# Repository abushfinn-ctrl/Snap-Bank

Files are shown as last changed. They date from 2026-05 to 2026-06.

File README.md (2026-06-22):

# Snap-Bank
A powerbank with a removable 18650 battery for quick "charges" on the go. I love the idea of this project because it allows you to only carry an extra or two 18650 batteries instead of having to carry a massive powerbank. This means that at school or scout camps I can keep a small powerbank in my pocket because I have really bad battery life on my phone, and I can still have the capacity of a 4 cell powerbank when I need via switching the batteries out. I also designed it that the battery holding can come fully out so you could carry an extra 18650 in the battery holder to keep it a little more protected, although I will probably end up printing a screw on case for the batteries. I also made it with a clear acrylic panel so I can see the cool internals that I spent time on.
# Final Product


# Pictures and Renders
Screenshot 2026-05-16 at 2 48 41 PM
Screenshot 2026-05-16 at 2 49 00 PM

# PCB
Screenshot 2026-05-16 at 2 46 15 PM
Screenshot 2026-05-16 at 2 47 12 PM
Screenshot 2026-05-16 at 2 46 44 PM

# BOM
|Part Number |Manufacturer Part Number|Description |Quantity|Unit Price CAD|Total Price CAD|Running total CAD|Unit Price USD|Total Price USD|Running total USD|Links |
|---|---|---|---|---|---|---|---|---|---|---|
|1276-1096-1-ND |CL21A106KOQNNNE |CAP CER 10UF 16V X5R 0805 |10 |$0.08 |$0.78 |$0.78 |$0.06 |$0.57 |$0.57 |https://www.digikey.ca/en/products/detail/samsung-electro-mechanics/CL21A106KOQNNNE/3886754 |
|1276-2909-1-ND |CL21A226MOQNNNE |CAP CER 22UF 16V X5R 0805 |5 |$0.39 |$1.95 |$2.73 |$0.28 |$1.42 |$1.98 |https://www.digikey.ca/en/products/detail/samsung-electro-mechanics/CL21A226MOQNNNE/3888567 |
|311-2.0ARCT-ND |RC0805JR-072RL |RES 2 OHM 5% 1/8W 0805 |4 |$0.15 |$0.60 |$3.33 |$0.11 |$0.44 |$2.42 |https://www.digikey.ca/en/products/detail/yageo/RC0805JR-072RL/728267 |
|311-20ARCT-ND |RC0805JR-0720RL |RES 20 OHM 5% 1/8W 0805 |2 |$0.15 |$0.30 |$3.63 |$0.11 |$0.22 |$2.64 |https://www.digikey.ca/en/products/detail/yageo/RC0805JR-0720RL/728281 |
|311-10KARCT-ND |RC0805JR-0710KL |RES 10K OHM 5% 1/8W 0805 |2 |$0.15 |$0.30 |$3.93 |$0.11 |$0.22 |$2.86 |https://www.digikey.ca/en/products/detail/yageo/RC0805JR-0710KL/728241 |
|311-5.1KARCT-ND |RC0805JR-075K1L |RES 5.1K OHM 5% 1/8W 0805 |10 |$0.05 |$0.45 |$4.38 |$0.03 |$0.33 |$3.18 |https://www.digikey.ca/en/products/detail/yageo/RC0805JR-075K1L/728338 |
|2073-USB4085-GF-ACT-ND |USB4085-GF-A |CONN RCPT USB2.0 TYPE C 16+8POS |2 |$1.31 |$2.62 |$7.00 |$0.95 |$1.90 |$5.09 |https://www.digikey.ca/en/products/detail/gct/USB4085-GF-A/9859662 |
|587-LAXHG6060YEL1R0NMRCT-ND|LAXHG6060YEL1R0NMR |FIXED IND 1UH 6.2A 13 MOHM SMD  |2 |$0.95 |$1.90 |$8.90 |$0.69 |$1.38 |$6.47 |https://www.digikey.ca/en/products/detail/taiyo-yuden/LAXHG6060YEL1R0NMR/17831610 |
|EG5350CT-ND |TL3305AF160QG |SWITCH TACTILE SPST-NO 0.05A 12V|2 |$0.31 |$0.62 |$9.52 |$0.23 |$0.45 |$6.92 |https://www.digikey.ca/en/products/detail/e-switch/TL3305AF160QG/5816181 |
|N/A |Digikey Shipping |Shipping for digikey |1 |$8.00 |$8.00 |$17.52 |$5.82 |$5.82 |$12.74 | |
|N/A |HST |Taxes for Digikey |1 |$2.28 |$2.28 |$19.80 |$1.66 |$1.66 |$14.40 | |
|IP5306 |Aliexpress |IP5306 from aliexpress (10 Pack)|1 |3.47 |3.47 |$23.27 |$2.52 |$2.52 |$16.92 |https://www.aliexpress.com/item/1005006842113401.html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 |
|18650 |Aliexpress |INR18650 25R 1865 2500Mah (4 Pack)|1 |19.66 |19.66 |$42.93 |$14.29 |$14.29 |$31.21 |https://www.aliexpress.com/item/1005009553868764.html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|

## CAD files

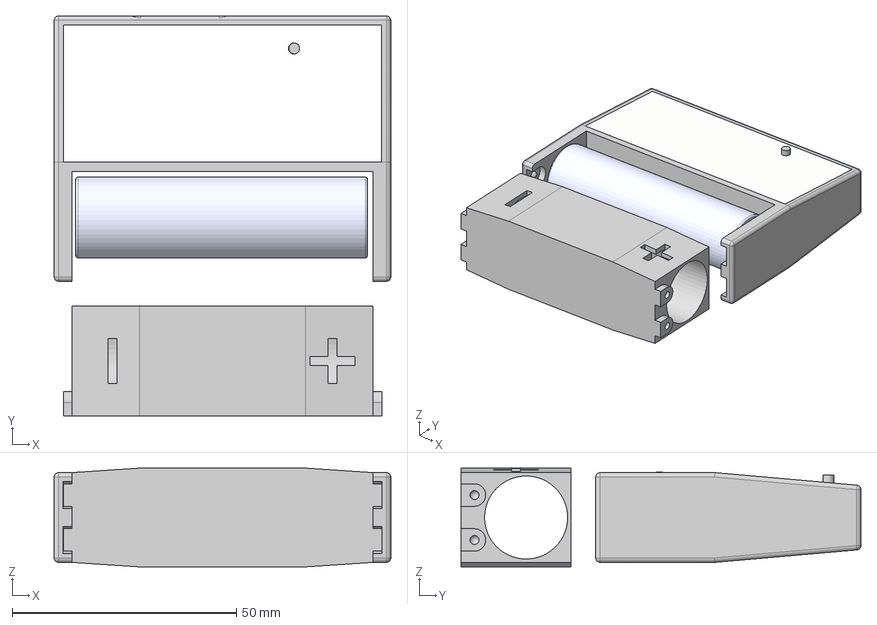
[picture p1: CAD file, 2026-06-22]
CAD/Powerbank.step
75.0 x 89.1 x 22.0 mm
LED_0805_2012Metric x 5
R_0805_2012Metric x 15
USB_C_Receptacle_GCT_USB4085 x 2
L_Chilisin_BWVS00606020
SW_SPST_TL3305A
Powerbank_PCB
battery 186501^battery 18650(2)_battery 18650
battery 186502^battery 18650(2)_battery 18650
battery 186503^battery 18650(2)_battery 18650
battery 186504^battery 18650(2)_battery 18650

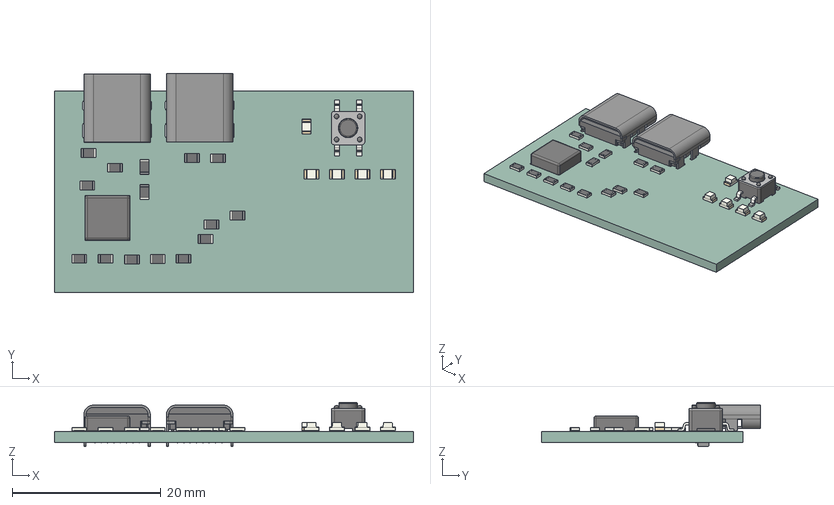
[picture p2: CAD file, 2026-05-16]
PCB/Snap-Bank/Powerbank.step
48.2 x 29.3 x 5.91 mm
LED_0805_2012Metric x 5
R_0805_2012Metric x 15
USB_C_Receptacle_GCT_USB4085 x 2
L_Chilisin_BWVS00606020
SW_SPST_TL3305A
Powerbank_PCB

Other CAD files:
CAD/SnapBank.f3z

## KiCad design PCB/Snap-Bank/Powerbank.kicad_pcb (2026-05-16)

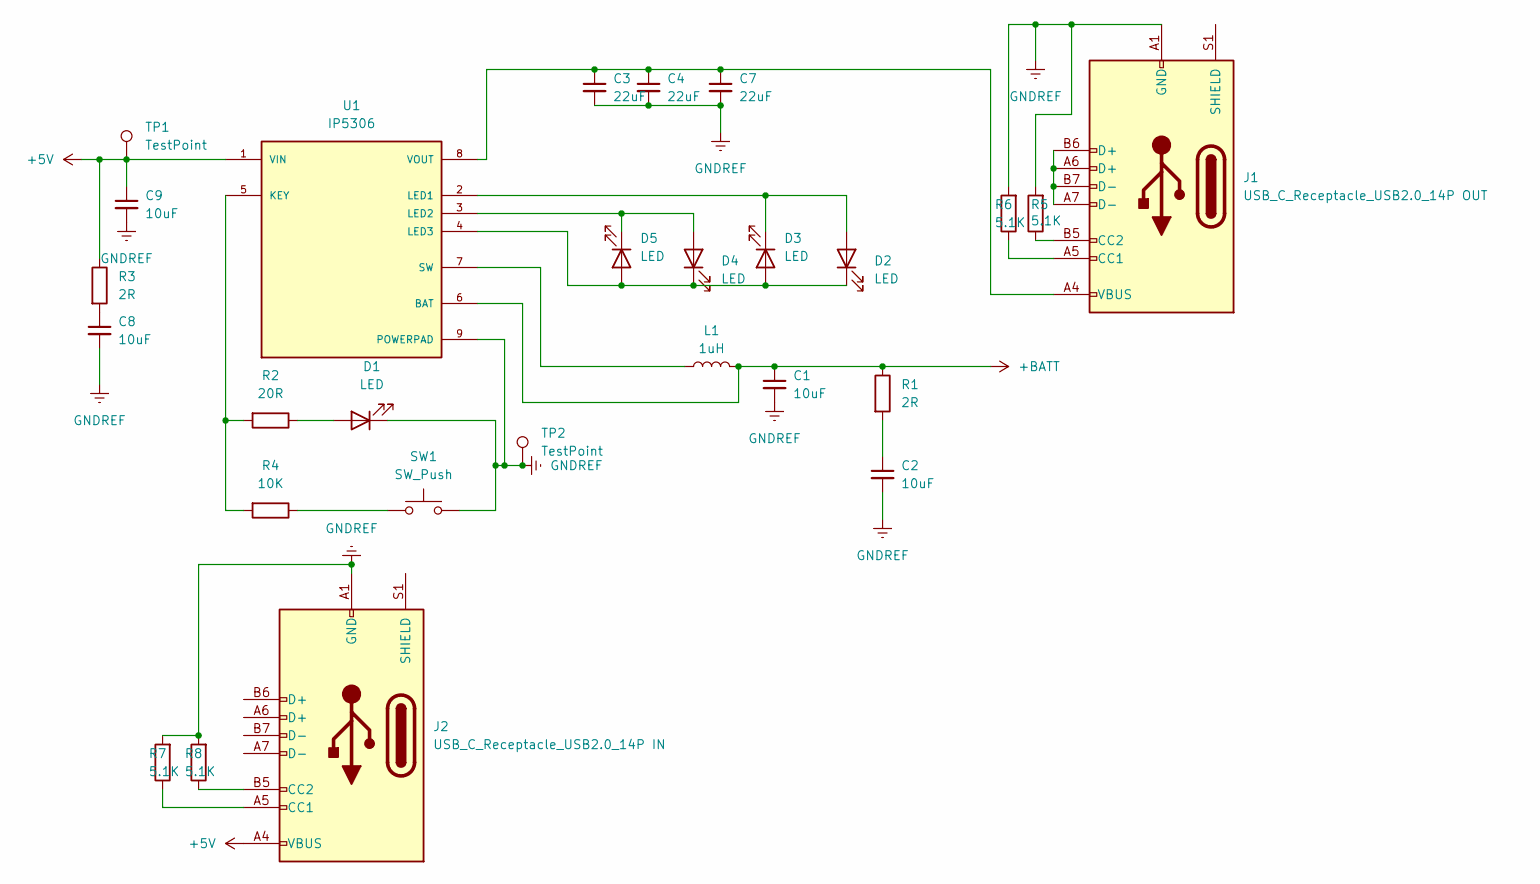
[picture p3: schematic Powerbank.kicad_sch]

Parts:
C1, C2, C8, C9: 10uF; R_0805_2012Metric
C3, C4, C7: 22uF; R_0805_2012Metric
D1, D2, D3, D4, D5: LED; LED_0805_2012Metric
J1: USB_C_Receptacle_USB2.0_14P OUT; USB_C_Receptacle_GCT_USB4085
J2: USB_C_Receptacle_USB2.0_14P IN; USB_C_Receptacle_GCT_USB4085
L1: 1uH; L_Chilisin_BWVS00606020
R1, R3: 2R; R_0805_2012Metric
R2: 20R; R_0805_2012Metric
R4: 10K; R_0805_2012Metric
R5, R6, R7, R8: 5.1K; R_0805_2012Metric
SW1: SW_Push; SW_SPST_TL3305A
TP1, TP2: TestPoint; TestPoint_Pad_D2.0mm
U1: IP5306; SOP127P600X165-9N; PARTREV 1.31

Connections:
+5V: C9.1, J2.A4 (VBUS), J2.A9 (VBUS), J2.B4 (VBUS), J2.B9 (VBUS), R3.1, TP1.1, U1.1 (VIN)
+BATT: C1.1, L1.2, R1.1, U1.6 (BAT)
GNDREF: C1.2, C2.2, C3.2, C4.2, C7.2, C8.2, C9.2, D1.1 (K), J1.A1 (GND), J1.A12 (GND), J1.B1 (GND), J1.B12 (GND), J2.A1 (GND), J2.A12 (GND), J2.B1 (GND), J2.B12 (GND), R5.2, R6.2, R7.2, R8.2, SW1.2, TP2.1, U1.9 (POWERPAD)
unnamed: C2.1, R1.2
unnamed: C8.1, R3.2
unnamed: D1.2 (A), R2.1
unnamed: D2.2 (A), D3.1 (K), U1.2 (LED1)
unnamed: D2.1 (K), D3.2 (A), D4.1 (K), D5.2 (A), U1.4 (LED3)
unnamed: D4.2 (A), D5.1 (K), U1.3 (LED2)
unnamed: J1.A5 (CC1), R6.1
unnamed: J1.B5 (CC2), R5.1
unnamed: J1.A6 (D+), J1.A7 (D-), J1.B6 (D+), J1.B7 (D-)
unnamed: J2.A5 (CC1), R7.1
unnamed: J2.B5 (CC2), R8.1
unnamed: R4.1, SW1.1
unnamed: R2.2, R4.2, U1.5 (KEY)
unnamed: L1.1, U1.7 (SW)
unnamed: C3.1, C4.1, C7.1, J1.A4 (VBUS), J1.A9 (VBUS), J1.B4 (VBUS), J1.B9 (VBUS), U1.8 (VOUT)

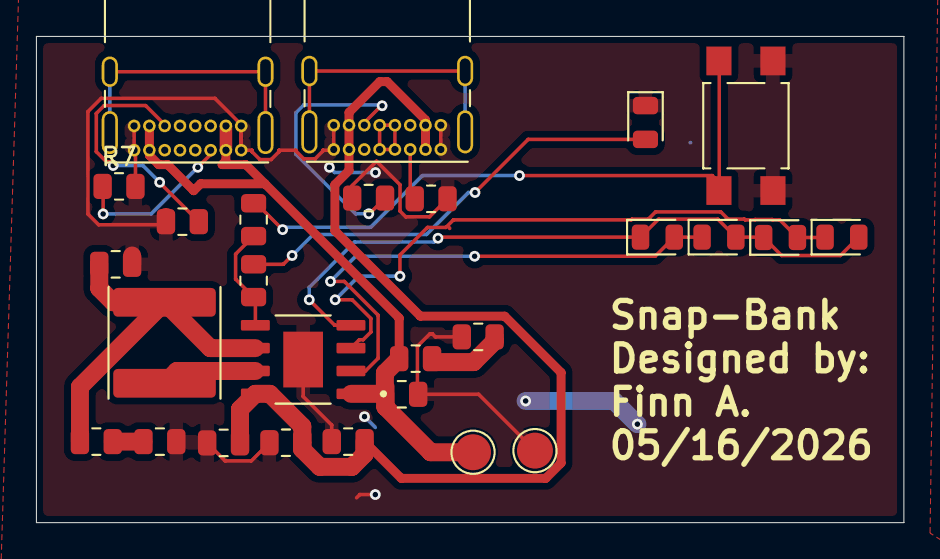
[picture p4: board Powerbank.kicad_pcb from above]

Board: 2 copper layers, 48.2 x 27.0 mm, 27 parts (0 on the bottom side), 18 nets.
